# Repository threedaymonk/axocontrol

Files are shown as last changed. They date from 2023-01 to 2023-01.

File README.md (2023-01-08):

# Axoloti control board

A control board for the [Axoloti Core](http://www.axoloti.com/) board.

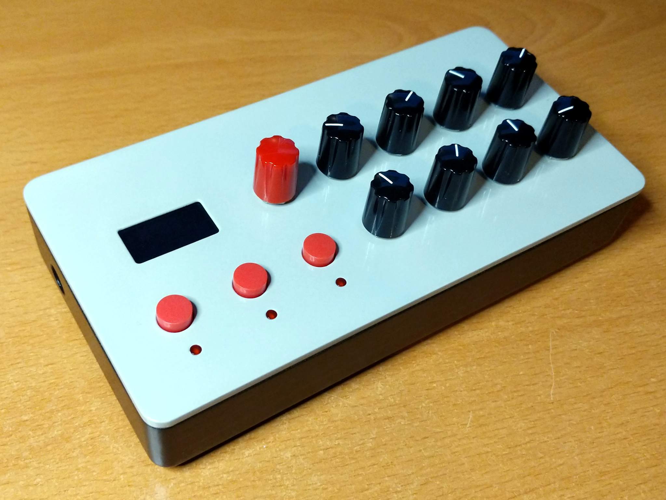
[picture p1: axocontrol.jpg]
The finished product


Inspired by [Tom Whitwell's Axo
Control](https://github.com/TomWhitwell/Axo-Control), but adds a rotary encoder
and an I2C OLED screen and removes the joystick.

## Features:

- 8 potentiometers
- Rotary encoder with switch
- 3 push buttons
- 3 LEDs (below buttons)
- OLED screen

## Bill of materials

| Qty | Ref | Part | Notes  |
| --- | --- | ---- | --- |
| 8 | RV1-8 | 9mm potentiometer B10k | [Thonk](https://www.thonk.co.uk/shop/alpha-9mm-pots-dshaft/) |
| 3 | SW1-3 | C&K tactile switch | [Thonk](https://www.thonk.co.uk/shop/radio-music-switch/) |
| 1 | SW4 | Encoder with switch | [Bourns PEC11R-4220F-S0024](https://www.mouser.co.uk/ProductDetail/Bourns/PEC11R-4220F-S0024) matches the above potentiometers in height |
|  10 | C1-9 | Capacitor 0603 100n | Might not be needed, can also try 10n for C9 and C10 |
| 3 | R1-3 | Resistor 0603 1k | |
| 2 | R5, R6 | Resistor 0603 10k | |
| 3 | D1-3 | 3mm LED | |
| 1 | | 0.96" White I2C SSD1306 OLED | Pin order VCC GND SCL SDA, e.g. [Banggood](https://uk.banggood.com/5Pcs-0_96-Inch-4Pin-White-IIC-I2C-OLED-Display-Module-12864-LED-p-971295.html) |
| 1 | | 1×40 2.54mm header | |
| 1 | | 1×40 2.54mm socket | |
| 1 | | 1900H knob without line | [Thonk](https://www.thonk.co.uk/shop/1900h-d/) |
| 8 | | 1900H knob with line | [Thonk](https://www.thonk.co.uk/shop/1900h-d/) |
| 8 | | 1.4mm dia × 4mm screw for plastic | For mounting screen: [Bitsbox](https://www.bitsboxuk.com/index.php?main_page=product_info&cPath=238_241&products_id=3443) |
| 6 | | M3 × 8mm screw | |
| 6 | | M3 × 11mm threaded standoff | |

## Hardware

OpenSCAD files for hardware are provided:

- axo-base.scad: lower part of enclosure
- axo-top.scad: upper part of enclosure
- ssd1306-riser.scad: riser for the display to bring it to the same height as
  the controls, so that it sits just below the front panel

## Connections

    OLED       ENC      RV1  RV2  RV3  RV4
    SDA PB9    SW PB6   PC3  PC4  PA0  PB1
    SCL PB8    A  PB7
               B  PC0

    SW1   SW2   SW3     RV5  RV6  RV7  RV8
    PC1   PC2   PC5     PA4  PA6  PA7  PB0

    LED1  LED2  LED3
    PA1   PA2   PA3

## Reuse

<br />This work is licensed under a <a rel="license" href="http://creativecommons.org/licenses/by-sa/4.0/">Creative Commons Attribution-ShareAlike 4.0 International License</a>.

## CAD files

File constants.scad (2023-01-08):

$fs = $preview ? 1 : 0.1;
$fa = $preview ? 3 : 2;
$e = 0.001;

module_sx = 160;
module_sy = 80;
module_sz = 24;

corner_r = 6;

wall_th = 2;
base_th = 3.2;

panel_th = 0.8;
top_th = 3;

gap_z = 3;
pcb_th = 1.6;
gap_x = 3;
gap_y = 1;

size_x = module_sx + 2 * wall_th + 2 * gap_x;
size_y = module_sy + 2 * wall_th + 2 * gap_y;
size_z = module_sz + base_th + gap_z - top_th + panel_th;

bosses = [
  // x, y, height
  [3.5, 10, gap_z],
  [3.5, module_sy - 10, gap_z + pcb_th],
  [3.5, 10 + (module_sy - 20) / 2, 0],
  [module_sx - 3.5, 10, gap_z],
  [module_sx - 3.5, module_sy - 10, gap_z + pcb_th],
  [module_sx - 3.5, 10 + (module_sy - 20) / 2, 0],
];

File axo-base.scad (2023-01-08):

include <rounded.scad>
include <constants.scad>

module shell() {
  difference() {
    rounded_bottom_cube(
      [size_x, size_y, size_z],
      r = corner_r,
      square_off = 1
    );
    translate([wall_th, wall_th, base_th])
      rounded_bottom_cube(
        [size_x - 2 * wall_th,
         size_y - 2 * wall_th,
         size_z],
        r = corner_r - wall_th
      );
  }
}

module boss(h, pos = true) {
  hole_d = 3.5;
  inner_d = 4;
  outer_d = 6;
  head_d = 6.5;
  head_depth = 2.6;
  chamfer = min(h, 1.4);

  if (pos) {
    difference() {
      union() {
        cylinder(d = outer_d, h = base_th + h);
        translate([0, 0, base_th - $e])
          cylinder(d1 = outer_d + 2 * chamfer, d2 = outer_d, h = chamfer + $e);
      }
      translate([0, 0, -$e])
        cylinder(d = inner_d, h = base_th + h + 2 * $e);
    }
  } else {
    translate([0, 0, -$e]) {
      cylinder(d = head_d, h = head_depth + $e);
      cylinder(d = hole_d, h = base_th + h + 2 * $e);
    }
  }
}

module bosses(pos = true) {
  translate([wall_th + gap_x, wall_th + gap_y, base_th])
    for(xyh = bosses)
      translate([xyh[0], xyh[1], 0])
        if (xyh[2] > 0)
          screw_boss(height = xyh[2], chamfer = [0.5, 3], pos = pos);
}

module cutouts() {
  translate([0, 0, base_th + gap_z + pcb_th]) {
    // Barrel connector
    translate([size_x - wall_th - 1, wall_th + gap_y + 15, -1])
      cube([wall_th + 1 - 0.8, 11, 13]);
    translate([size_x - wall_th, wall_th + gap_y + 20.5, 6.5])
      rotate([0, 90, 0])
        cylinder(d=9, h=20, center=true);

    translate([wall_th + gap_x, wall_th + 2, 0]) {
      rotate([90, 0, 0]) linear_extrude(height = 10) {
        // Audio
        translate([17.5, 8, 0]) circle(d=12.5);
        translate([37, 8, 0]) circle(d=12.5);
        // Micro USB
        translate([63, 1.5, 0]) rounded_square([12, 8], center=true);
        // USB A
        translate([87, 7.2, 0]) rounded_square([8, 16], r=1, center=true);
        // LEDs
        translate([93.5, 0.4, 0]) circle(d=2);
        translate([97, 0.4, 0]) circle(d=2);
        // Switches
        translate([101.5, 0.5, 0]) circle(d=4);
        translate([107, 0.5, 0]) circle(d=4);
        // MIDI
        hull() {
          translate([121.5, 10, 0]) circle(d=18);
          translate([142, 10, 0]) circle(d=18);
        }

        // Merge Micro USB, Micro SD, and USB A
        translate([69.5, 2, 0]) rounded_square([43, 9], r=1, center=true);
      }
    }
    // Bottom access for Micro SD
    translate([wall_th + gap_x + 76 - 14/2, -10, -20])
      rounded_cube([14, 16.5, 20 + 2.2], r = 1);
  }
}

module feet() {
  // Feet
  foot_d = 10.5;
  foot_x = 20;
  foot_y = 12;
  foot_depth = 1.2;
  feet = [
    [foot_x, foot_y],
    [size_x - foot_x, foot_y],
    [foot_x, size_y - foot_y],
    [size_x - foot_x, size_y - foot_y],
  ];
  for (foot = feet)
    translate([foot[0], foot[1], -1])
      cylinder(d = foot_d, h = foot_depth + 1);
}


difference() {
  union() {
    shell();
    bosses(pos = true);
  }
  bosses(pos = false);
  cutouts();
  feet();
}

if ($preview) {
  translate([module_sx + wall_th + gap_x, wall_th + gap_y, pcb_th + base_th + gap_z])
    rotate([90, 0, 180])
      import("axoloti.stl");
}

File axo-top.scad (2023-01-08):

include <rounded.scad>
include <constants.scad>

margin = gap_x + 7;
frame_th = top_th + 2;
frame_sx = size_x - 2 * wall_th;
frame_sy = size_y - 2 * wall_th;


pot_d = 8;
button_d = 10;
led_d = 3.0;
x_off = 14 + wall_th + gap_x;
y_off = wall_th + gap_y;
h_pitch = 22;

module panel() {
  linear_extrude(height = top_th) {
    rounded_square([size_x, size_y], r = corner_r);
  }
  linear_extrude(height = frame_th) {
    translate([wall_th, wall_th]) {
      difference() {
        rounded_square([frame_sx, frame_sy], r = corner_r - wall_th);
        translate([2, 2])
          rounded_square([frame_sx - 4, frame_sy - 4], r = corner_r - wall_th - 2);
      }
    }
  }
}

module panel_cutouts(height) {
  linear_extrude(height = height) {
    // Top row pots and encoder
    for(i = [2 : 6])
      translate([x_off + i * h_pitch, y_off + 32])
        circle(d = pot_d);

    // Bottom row pots
    for(i = [3 : 6])
      translate([x_off + i * h_pitch, y_off + 57])
        circle(d = pot_d);

    // Buttons
    for(i = [0 : 2])
      translate([x_off + i * h_pitch, y_off + 57])
        circle(d = button_d);

    // LEDs
    for(i = [0 : 2])
      translate([x_off + i * h_pitch, y_off + 68.5])
        circle(d = led_d);

    // Screen
    translate([x_off + 11, y_off + 31])
      rounded_square([25.5, 13.5], center=true, r=1);
  }
}

module frame_insets(height) {
  linear_extrude(height = height) {
    difference() {
      translate([wall_th + margin, wall_th + margin]) {
        rounded_square([frame_sx - 2*margin, frame_sy - 2*margin], r = corner_r - wall_th);
      }
      for(i = [1 : 5]) {
        translate([x_off + (i + 0.5) * h_pitch, size_y / 2])
          square([2, size_y], center=true);
      }
    }

    // MIDI connector
    translate([wall_th + gap_x + 6, wall_th + gap_y - 1])
      square([43, 4 + gap_y]);
  }
}

difference() {
  panel();
  translate([0, 0, -$e]) panel_cutouts(frame_th);
  translate([0, 0, panel_th]) frame_insets(frame_th);
}

// Bosses for M3 screws
translate([wall_th + gap_x, wall_th + gap_y])
  for(xyh = bosses)
    translate([xyh[0], xyh[1], top_th])
      screw_boss(
        height = 10 + panel_th - top_th,
        chamfer = [0.5, 3],
        inner_dia = 2.8,
        outer_dia = 6,
        pos = true
      );

// Bosses for support
for (y = [wall_th + margin / 2, size_y - wall_th - margin / 2])
  for (x = [wall_th + gap_x + 60, wall_th + gap_x + 100])
    translate([x, y, top_th])
      screw_boss(
        height = 10 + panel_th - top_th,
        chamfer = [3, 0.5],
        pos = true
      );

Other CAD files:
rounded.scad
ssd1306-riser.scad

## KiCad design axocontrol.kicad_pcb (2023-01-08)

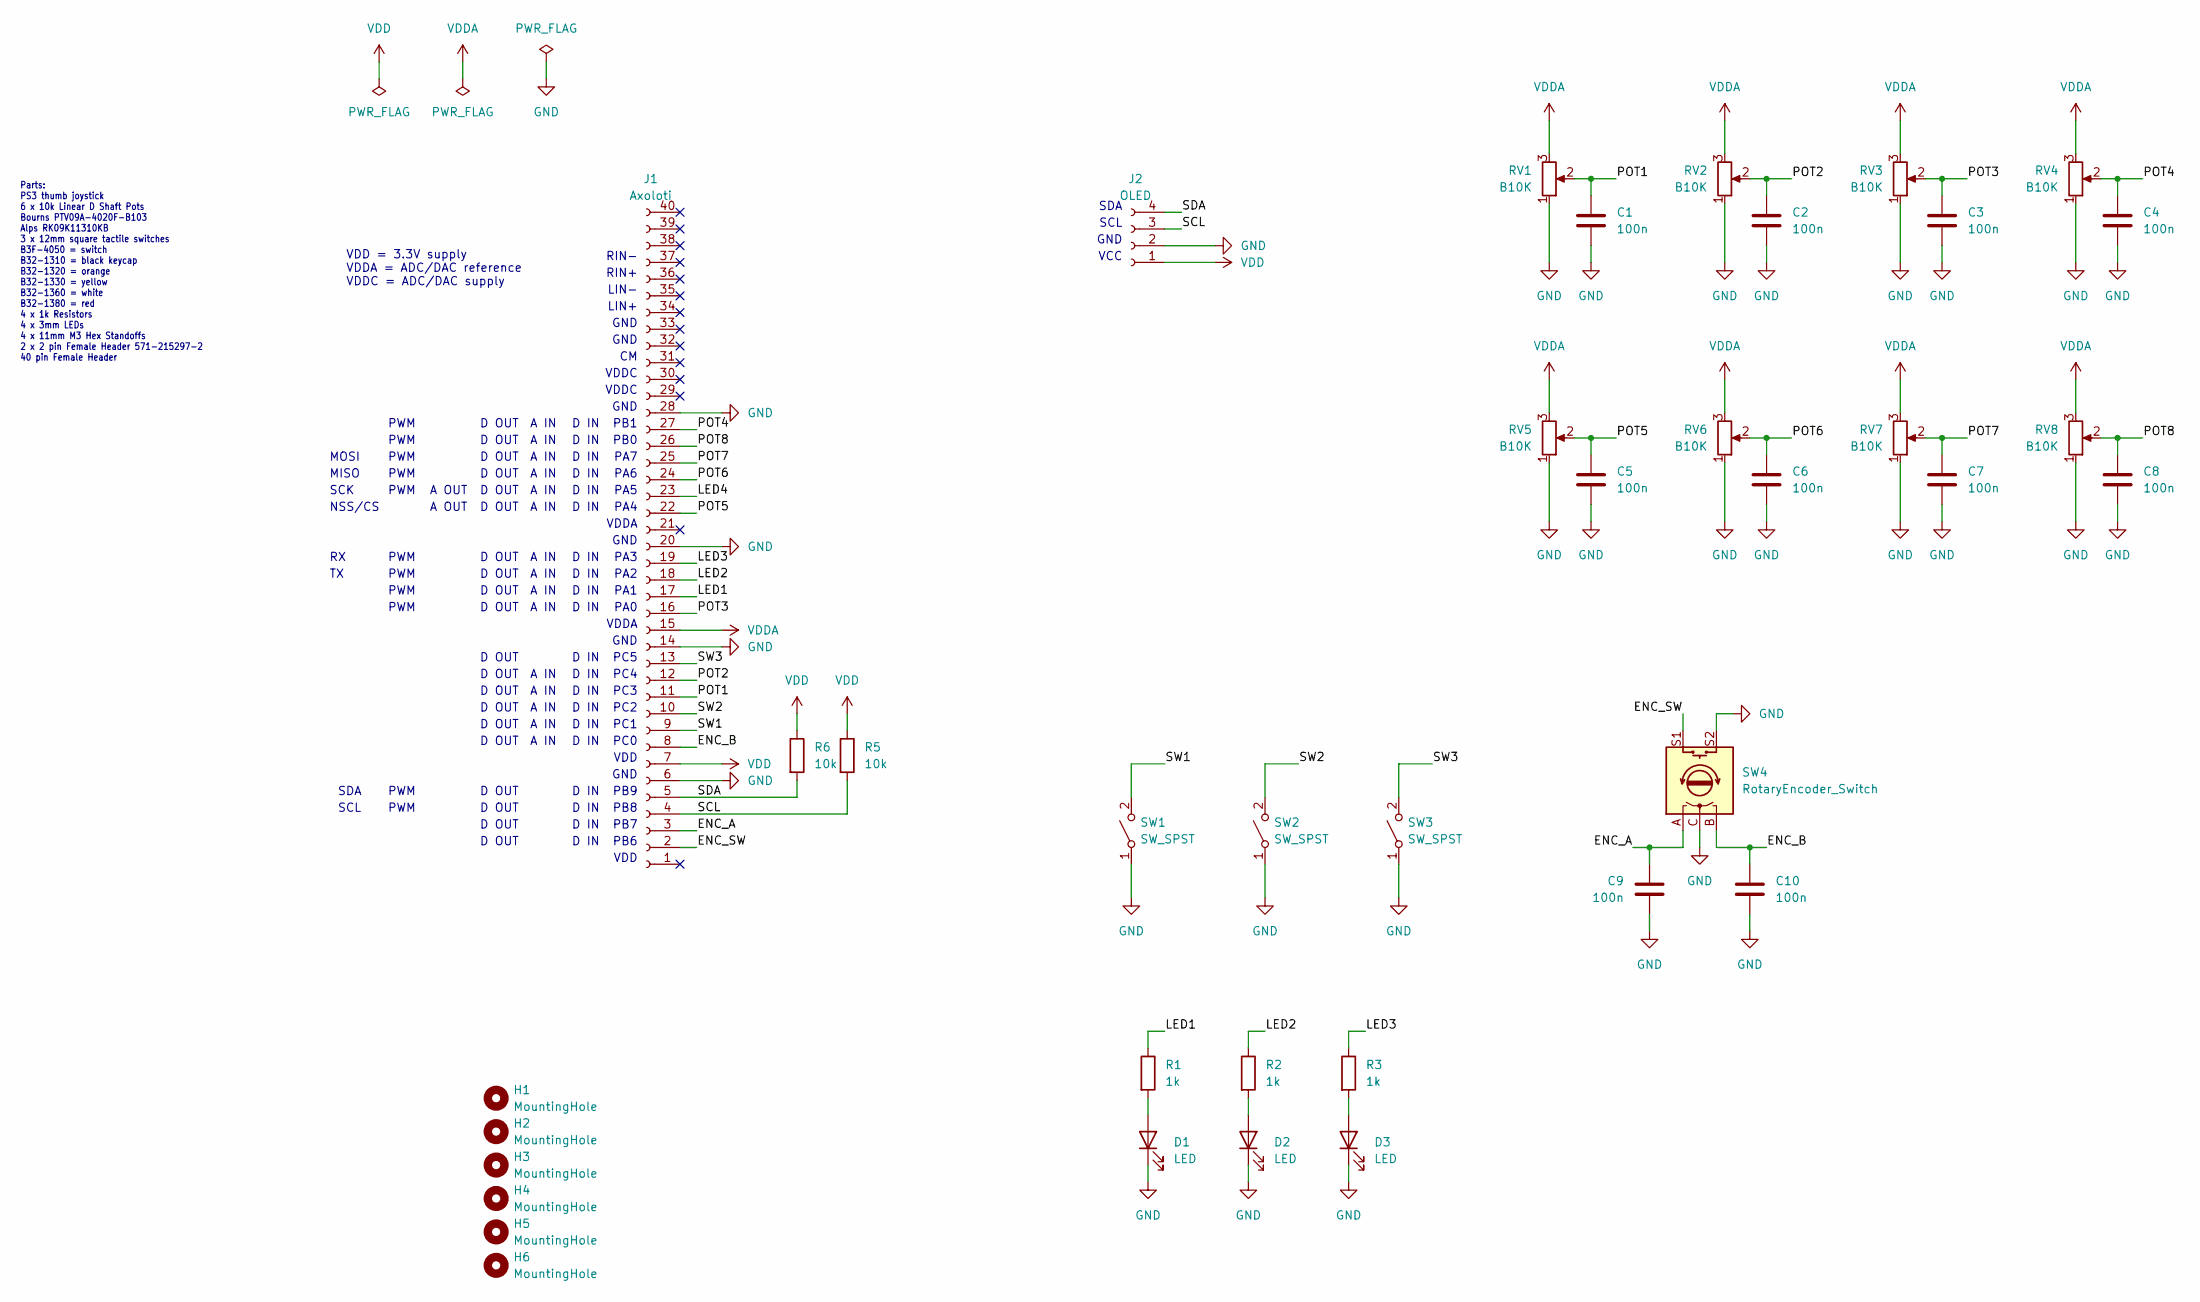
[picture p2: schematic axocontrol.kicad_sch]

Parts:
C1, C2, C3, C4, C5, C6, C7, C8, C9, C10: 100n; C_0603_1608Metric_Pad1.08x0.95mm_HandSolder
D1, D2, D3: LED; LED_D3.0mm
H1, H2, H3, H4, H5, H6: MountingHole; MountingHole_3mm
J1: Axoloti; PinSocket_1x40_P2.54mm_Vertical
J2: OLED; OLED_128x64
R1, R2, R3: 1k; R_0603_1608Metric_Pad0.98x0.95mm_HandSolder
R5, R6: 10k; R_0603_1608Metric_Pad0.98x0.95mm_HandSolder
RV1, RV2, RV3, RV4, RV5, RV6, RV7, RV8: B10K; Alpha_9mm_Pot
SW1, SW2, SW3: SW_SPST; CK_D6R90_Push_Switch_SPST
SW4: RotaryEncoder_Switch; Bourns_PEC11R_Encoder_Switch; Mouser 652-PEC11R-4220F-S24

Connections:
/ENC_A: C9.1, J1.3, SW4.A
/ENC_B: C10.1, J1.8, SW4.B
/ENC_SW: J1.2, SW4.S1
/LED1: J1.17, R1.1
/LED2: J1.18, R2.1
/LED3: J1.19, R3.1
/LED4: J1.23
/POT1: C1.1, J1.11, RV1.2; also elsewhere on the board
/POT2: C2.1, J1.12, RV2.2
/POT3: C3.1, J1.16, RV3.2
/POT4: C4.1, J1.27, RV4.2
/POT5: C5.1, J1.22, RV5.2
/POT6: C6.1, J1.24, RV6.2
/POT7: C7.1, J1.25, RV7.2; also elsewhere on the board
/POT8: C8.1, J1.26, RV8.2
/SCL: J1.4, J2.3, R5.2
/SDA: J1.5, J2.4, R6.2
/SW1: J1.9, SW1.2 (B)
/SW2: J1.10, SW2.2 (B)
/SW3: J1.13, SW3.2 (B)
GND: C1.2, C2.2, C3.2, C4.2, C5.2, C6.2, C7.2, C8.2, C9.2, C10.2, D1.1 (K), D2.1 (K), D3.1 (K), J1.6, J1.14, J1.20, J1.28, J2.2, RV1.1, RV2.1, RV3.1, RV4.1, RV5.1, RV6.1, RV7.1, RV8.1, SW1.1 (A), SW2.1 (A), SW3.1 (A), SW4.C, SW4.S2; also elsewhere on the board
unnamed: D1.2 (A), R1.2
unnamed: D2.2 (A), R2.2
unnamed: D3.2 (A), R3.2
VDD: J1.7, J2.1, R5.1, R6.1
VDDA: J1.15, RV1.3, RV2.3, RV3.3, RV4.3, RV5.3, RV6.3, RV7.3, RV8.3; also elsewhere on the board

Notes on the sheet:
PB8
PWM
D OUT
MISO
A IN
D IN
RIN+
PA4
PA5
PB0
PB1
NSS/CS
VDDA
PA7
PB9
PA0
MOSI
PC1
SDA
PC5
VDD = 3.3V supply VDDA = ADC/DAC reference VDDC = ADC/DAC supply
GND
PA3
VDDC
Parts: PS3 thumb joystick 6 x 10k Linear D Shaft Pots Bourns PTV09A-4020F-B103 Alps RK09K11310KB 3 x 12mm square tactile switches B3F-4050 = switch B32-1310 = black keycap B32-1320 = orange B32-1330 = yellow B32-1360 = white B32-1380 = red 4 x 1k Resistors 4 x 3mm LEDs 4 x 11mm M3 Hex Standoffs 2 x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
VDD
PA2
SCL
SCK
PC4
PA1
A OUT
LIN+
LIN-
PB7
PB6
PA6
PC0
PC2
RIN-

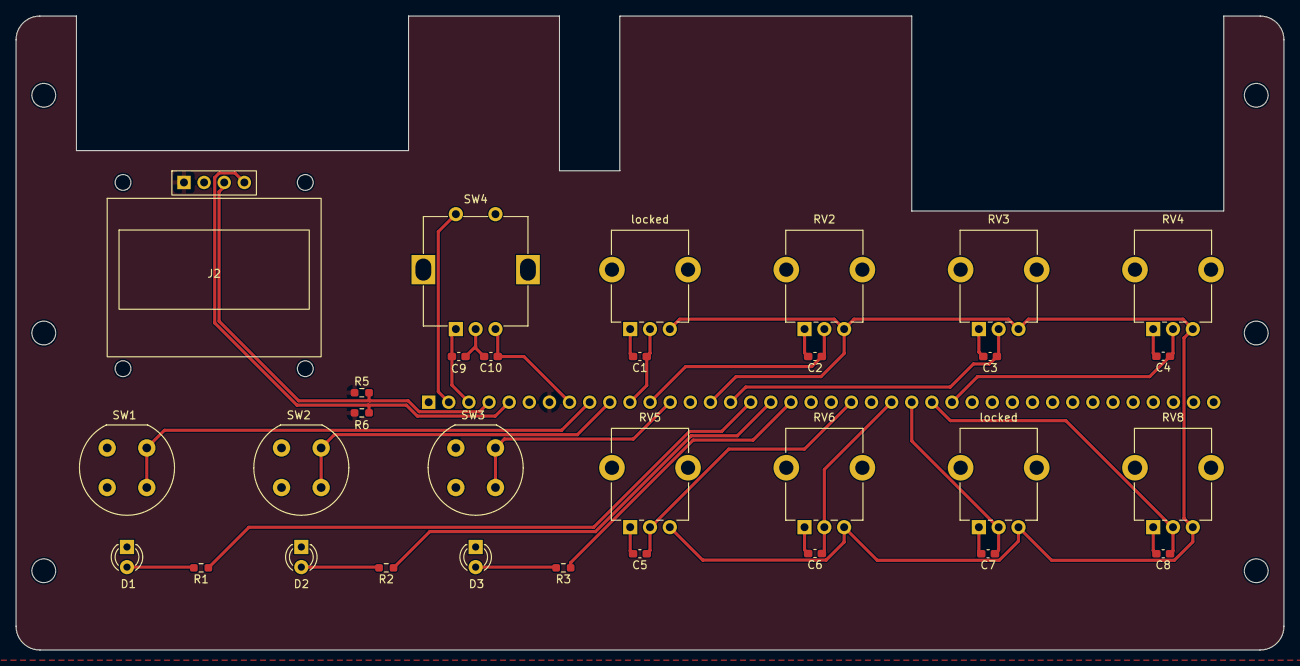
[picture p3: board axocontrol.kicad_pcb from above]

Board: 2 copper layers, 160.0 x 80.0 mm, 38 parts (1 on the bottom side), 25 nets.

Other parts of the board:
locked: B10K; Alpha_9mm_Pot
locked#2: B10K; Alpha_9mm_Pot
locked#3: MountingHole; MountingHole_3mm

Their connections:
/POT1: locked.2; also elsewhere on the board
/POT7: locked#2.2; also elsewhere on the board
GND: locked.1, locked#2.1; also elsewhere on the board
VDDA: locked.3, locked#2.3; also elsewhere on the board

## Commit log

2023-01-08 Initial PCB
    [axocontrol.kicad_pcb, axocontrol.kicad_sch]
2023-01-08 Model for case
    [case.scad, constants.scad, rounded.scad]
2023-01-08 Include headphone socket in merged slot
    [case.scad]
2023-01-08 Show model of board on preview
    Model from https://github.com/Believotron/3D-Models
    [case.scad]
2023-01-08 Move rounded rectangle to shared library
    It's called rounded_square for consistency.
    [case.scad]
2023-01-08 Add spacer/upper reinforcement
    [rounded.scad, spacer.scad]
2023-01-08 Generate top panel
    This needs manual tweaking in Inkscape, so the file generated is
    ignored in git.
    [acrylic.scad]
2023-01-08 Tweak spacer
    This also adds a front-to-back strut to stop flexing in the y axis.
    [rounded.scad, spacer.scad]
2023-01-08 Add front plate to spacer
    Laser cut acrylic is expensive, so let's not!
    [spacer.scad]
2023-01-08 Remove acrylic
    [acrylic.scad]
2023-01-08 Ignore stl files
2023-01-08 Rename models for easier printing
    [axo-base.scad, axo-top.scad]
2023-01-08 Increase gap on sides for easier fitting
    The barrel connector was very tight.
    [constants.scad]
2023-01-08 Enlarge gap around MIDI connectors
    The plugs wouldn't fit.
    [axo-base.scad]
2023-01-08 Use bosses developed for top
    [axo-base.scad]
2023-01-08 Enlarge window to fit OLED
    [axo-top.scad]
2023-01-08 Allow for paint around OLED
    [axo-top.scad]
2023-01-08 Make LED exact
    These can be finished with a drill.
    [axo-top.scad]
2023-01-08 Correct manifold of boss
    [rounded.scad]
2023-01-08 Use blind threaded inserts
    This makes the top panel nicer and simplifies assembly as everything can
    be screwed to the top plate.
    [axo-top.scad]
2023-01-08 Give top plate 3mm margin
    Also tweak screen position and reduce struts for quicker printing.
    [axo-base.scad, axo-top.scad, constants.scad]
2023-01-08 Tweak feet and power cutout
    [axo-base.scad]
2023-01-08 Add riser for screen
    [ssd1306-riser.scad]
2023-01-08 Add LEDs
